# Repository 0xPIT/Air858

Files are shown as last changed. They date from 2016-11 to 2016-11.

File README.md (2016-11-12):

# Air858

Simplified and optimized replacement controller for 
the low-cost W.E.P. 858D+ Hot Air Soldering Station.

## Warning


**This project operates with possibly lethal mains voltage. If you are unsure what to do, don't do it and get help from an experienced tinkerer with professional training.**

## Image of PCB rev. 1
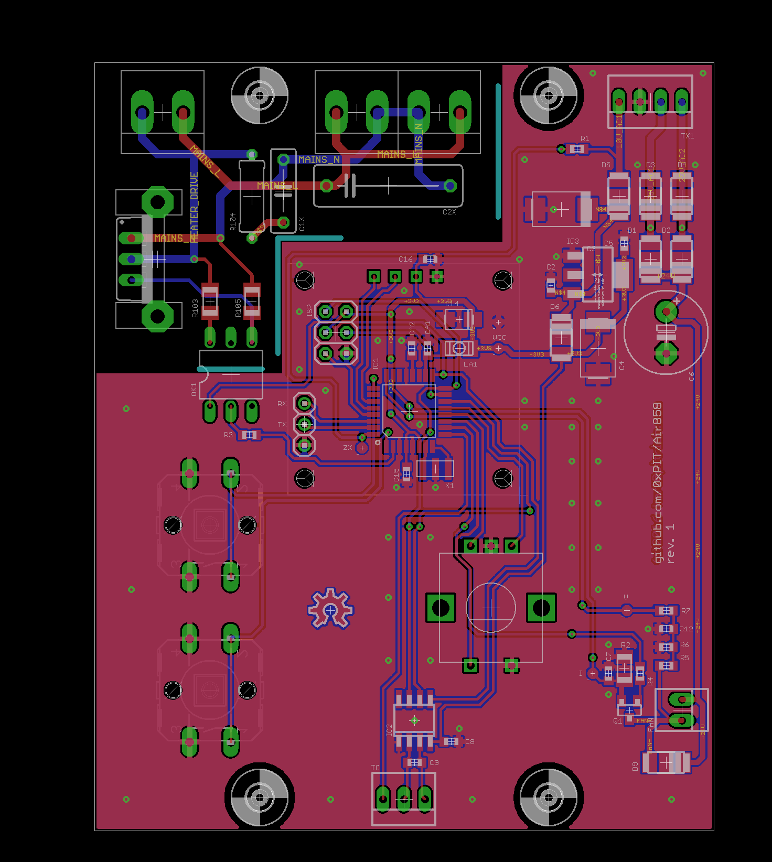
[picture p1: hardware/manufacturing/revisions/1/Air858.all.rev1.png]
BoardAllRev1


Licensing
====================
```
The MIT License (MIT)

Copyright (c) 2016 karl@pitrich.com
All rights reserved.

Permission is hereby granted, free of charge, to any person obtaining a copy
of this software and associated documentation files (the "Software"), to deal
in the Software without restriction, including without limitation the rights
to use, copy, modify, merge, publish, distribute, sublicense, and/or sell
copies of the Software, and to permit persons to whom the Software is
furnished to do so, subject to the following conditions:

The above copyright notice and this permission notice shall be included in
all copies or substantial portions of the Software.

THE SOFTWARE IS PROVIDED "AS IS", WITHOUT WARRANTY OF ANY KIND, EXPRESS OR
IMPLIED, INCLUDING BUT NOT LIMITED TO THE WARRANTIES OF MERCHANTABILITY,
FITNESS FOR A PARTICULAR PURPOSE AND NONINFRINGEMENT. IN NO EVENT SHALL THE
AUTHORS OR COPYRIGHT HOLDERS BE LIABLE FOR ANY CLAIM, DAMAGES OR OTHER
LIABILITY, WHETHER IN AN ACTION OF CONTRACT, TORT OR OTHERWISE, ARISING FROM,
OUT OF OR IN CONNECTION WITH THE SOFTWARE OR THE USE OR OTHER DEALINGS IN
THE SOFTWARE.
```

[BoardAllRev1]:https://raw.githubusercontent.com/0xPIT/Air858/master/hardware/manufacturing/revisions/1/Air858.all.rev1.png

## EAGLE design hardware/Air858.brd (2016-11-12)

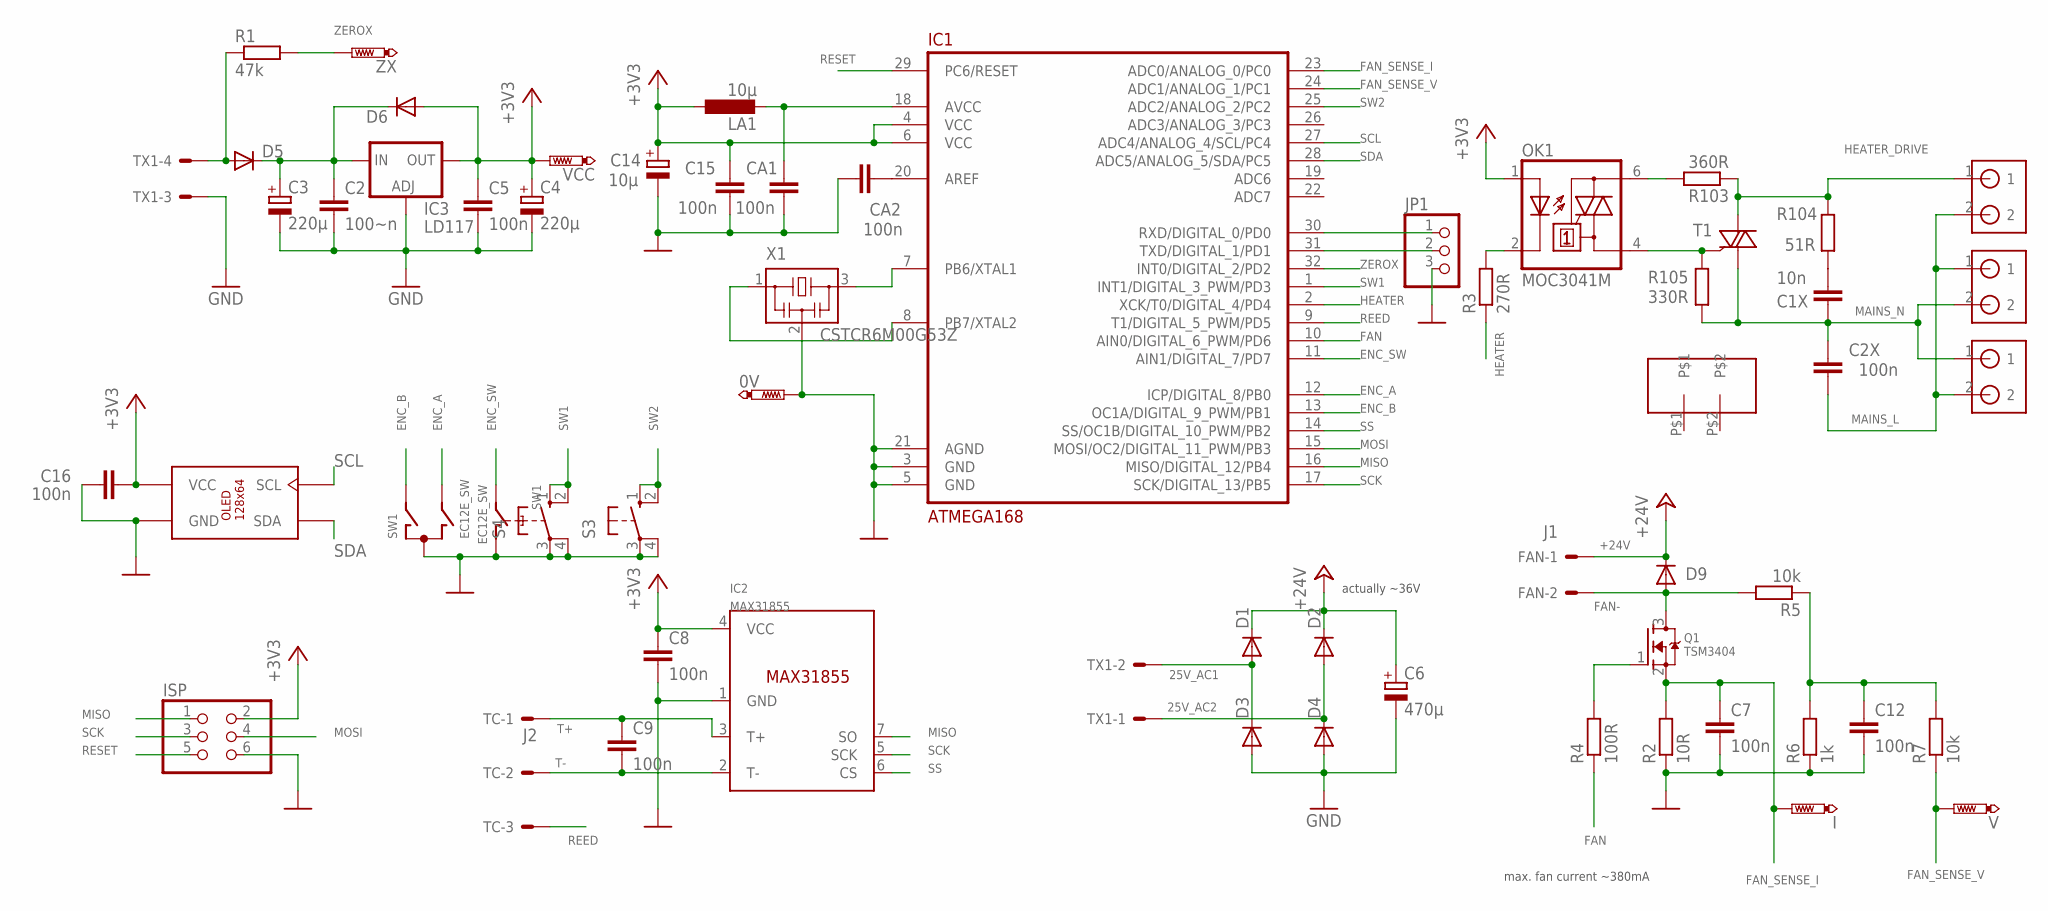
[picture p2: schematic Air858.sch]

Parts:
0V: PTR1B1,27; B1,27
C1X: 10n; C075-032X103
C2: 100~n; C0603
C2X: 100n; C150-054X183
C3, C4: 220µ; SMC_E
C5: 100n; C0603
C6: 470µ; E5-10,5
C7, C8, C9, C12, C15, C16: 100n; C0603K
C14: 10µ; B/3528-21W
CA1, CA2: 100n; C0603K
D1, D2, D3, D4, D5, D6, D9: DIODE-DO-214AC; DO-214AC
FAN: J1; 22-23-2021
HEATER: 2POL5MM
I: PTR1B1,27; B1,27
IC1: ATMEGA168; QFP32
IC2: MAX31855; SOIC8
IC3: LD117; SOT223
ISP: PINHD-2X3; 2X03
JP1: PINHD-1X3; 1X03
LA1: 10µ; L3225P
MAINS1, MAINS2: 2POL5MM
OK1: MOC3041M; DIL06
OLED1: SSD1306-IIC
Q1: TSM3404; SOT23
R1: 47k; R0603
R2: 10R; M1206
R3: 270R; R0603
R4: 100R; R0603
R5, R7: 10k; R0603
R6: 1k; R0603
R103: 360R; M1206
R104: 51R; 0309/10
R105: 330R; M1206
S3, S4: 40-XX; B3F-40XX
SW1: EC12E_SW; ALPS_EC12E_SW
T1: BTA16; TO220BV
TC: J2; 22-23-2031
TX1: J4; 22-23-2041
U$5: HEATSINK17X7.5TO220
V: PTR1B1,27; B1,27
VCC: PTR1B1,27; B1,27
X1: CSTCR6M00G53Z; CSTCR6M
ZX: PTR1B1,27; B1,27

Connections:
10V_AC1: D5.A, R1.1, TX1.4
25V_AC1: D1.A, D3.C, TX1.2
25V_AC2: D2.A, D4.C, TX1.1
+3V3: C4.+, C5.1, C8.1, C14.+, C15.1, C16.2, D6.A, IC1.4 (VCC), IC1.6 (VCC), IC2.4 (VCC), IC3.4 (OUT), ISP.2, LA1.1, OK1.1 (A), OLED1.VCC, VCC.TP
+24V: C6.+, D1.C, D2.C, D9.C, FAN.1
AREF: CA2.2, IC1.20 (AREF)
AVCC: CA1.1, IC1.18 (AVCC), LA1.2
ENC_A: IC1.12 (ICP/DIGITAL_8/PB0), SW1.B
ENC_B: IC1.13 (OC1A/DIGITAL_9_PWM/PB1), SW1.A
ENC_SW: IC1.11 (AIN1/DIGITAL_7/PD7), SW1.E (2)
FAN: IC1.10 (AIN0/DIGITAL_6_PWM/PD6), R4.1
FAN-: D9.A, FAN.2, Q1.3 (D), R5.2
FAN_SENSE_I: C7.1, I.TP, IC1.23 (ADC0/ANALOG_0/PC0), Q1.2 (S), R2.2
FAN_SENSE_V: IC1.24 (ADC1/ANALOG_1/PC1), R7.1, V.TP
GND: 0V.TP, C2.2, C3.-, C4.-, C5.2, C6.-, C7.2, C8.2, C12.2, C14.-, C15.2, C16.1, CA1.2, CA2.1, D3.A, D4.A, IC1.3 (GND), IC1.5 (GND), IC1.21 (AGND), IC2.1 (GND), IC3.1 (ADJ), ISP.6, JP1.3, OLED1.GND, R2.1, R6.1, S3.3, S3.4 (P1), S4.3, S4.4 (P1), SW1.C, SW1.D (1), TX1.3, X1.2
HEATER: IC1.2 (XCK/T0/DIGITAL_4/PD4), R3.1
HEATER_DRIVE: HEATER.1, R103.1, R104.2, T1.T2 (A2)
MAINS_L: C2X.1, HEATER.2, MAINS1.1, MAINS2.2
MAINS_N: C1X.1, C2X.2, MAINS1.2, MAINS2.1, R105.2, T1.T1 (A1)
MISO: IC1.16 (MISO/DIGITAL_12/PB4), IC2.7 (SO), ISP.1
MOSI: IC1.15 (MOSI/OC2/DIGITAL_11_PWM/PB3), ISP.4
unnamed: C12.1, R5.1, R6.2, R7.2
unnamed: OK1.6 (A2), R103.2
unnamed: C2.1, C3.+, D5.C, D6.C, IC3.3 (IN)
unnamed: OK1.2 (C), R3.2
unnamed: OK1.4 (A1), R105.1, T1.G
unnamed: C1X.2, R104.1
unnamed: IC1.7 (PB6/XTAL1), X1.3
unnamed: Q1.1 (G), R4.2
unnamed: IC1.8 (PB7/XTAL2), X1.1
REED: IC1.9 (T1/DIGITAL_5_PWM/PD5), TC.3
RESET: IC1.29 (PC6/RESET), ISP.5
RXD: IC1.30 (RXD/DIGITAL_0/PD0), JP1.1
SCK: IC1.17 (SCK/DIGITAL_13/PB5), IC2.5 (SCK), ISP.3
SCL: IC1.27 (ADC4/ANALOG_4/SCL/PC4), OLED1.SCL
SDA: IC1.28 (ADC5/ANALOG_5/SDA/PC5), OLED1.SDA
SS: IC1.14 (SS/OC1B/DIGITAL_10_PWM/PB2), IC2.6 (CS)
SW1: IC1.1 (INT1/DIGITAL_3_PWM/PD3), S4.1 (S), S4.2 (S1)
SW2: IC1.25 (ADC2/ANALOG_2/PC2), S3.1 (S), S3.2 (S1)
T+: C9.1, IC2.3 (T+), TC.1
T-: C9.2, IC2.2 (T-), TC.2
TXD: IC1.31 (TXD/DIGITAL_1/PD1), JP1.2
ZEROX: IC1.32 (INT0/DIGITAL_2/PD2), R1.2, ZX.TP

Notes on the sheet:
max. fan current ~380mA
actually ~36V

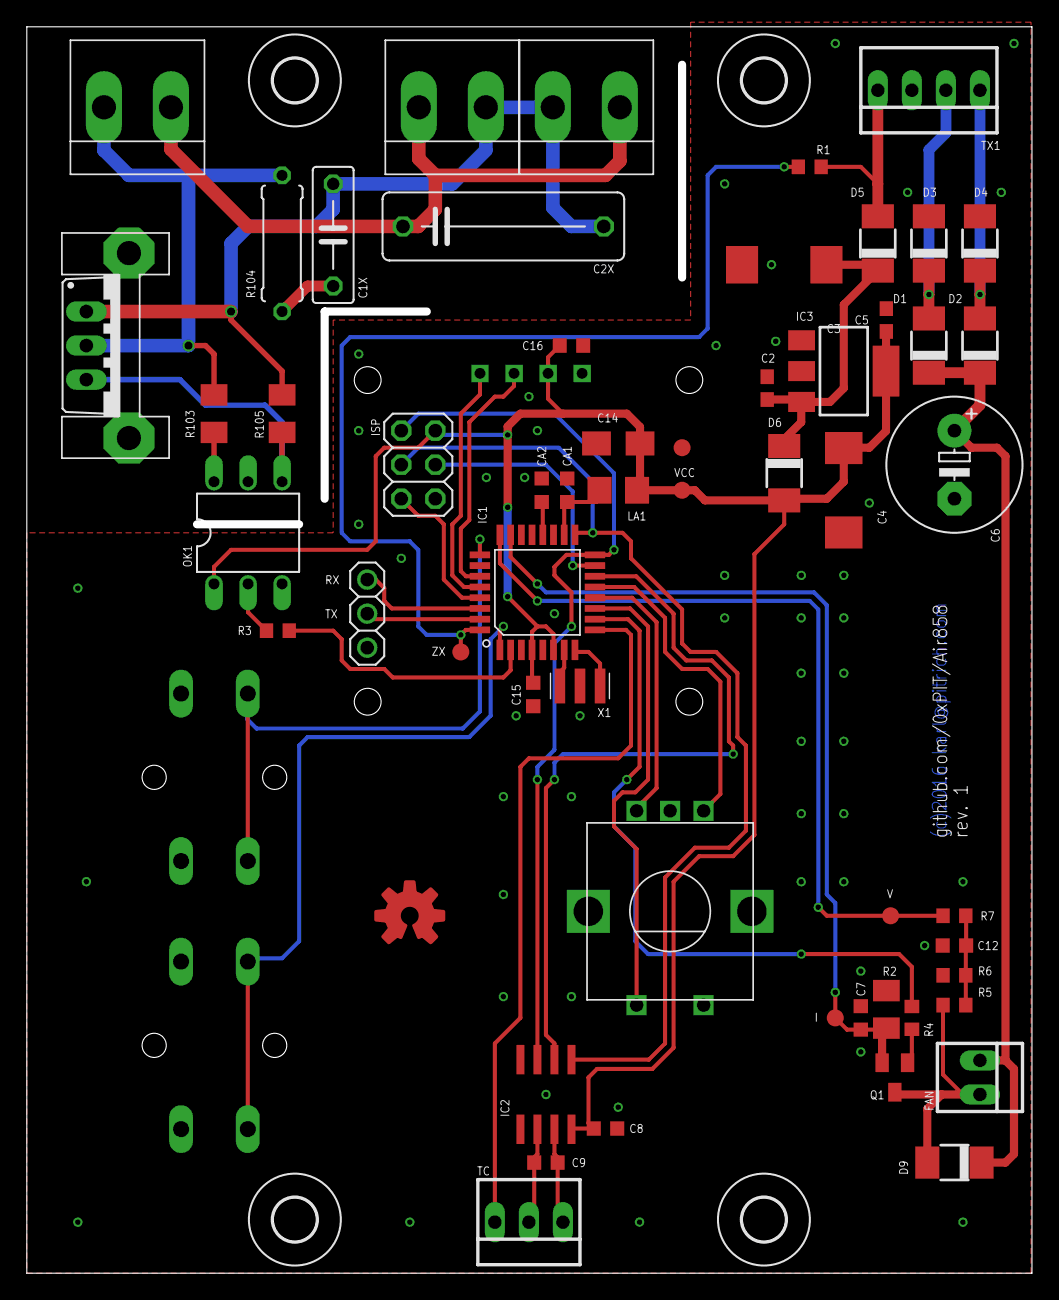
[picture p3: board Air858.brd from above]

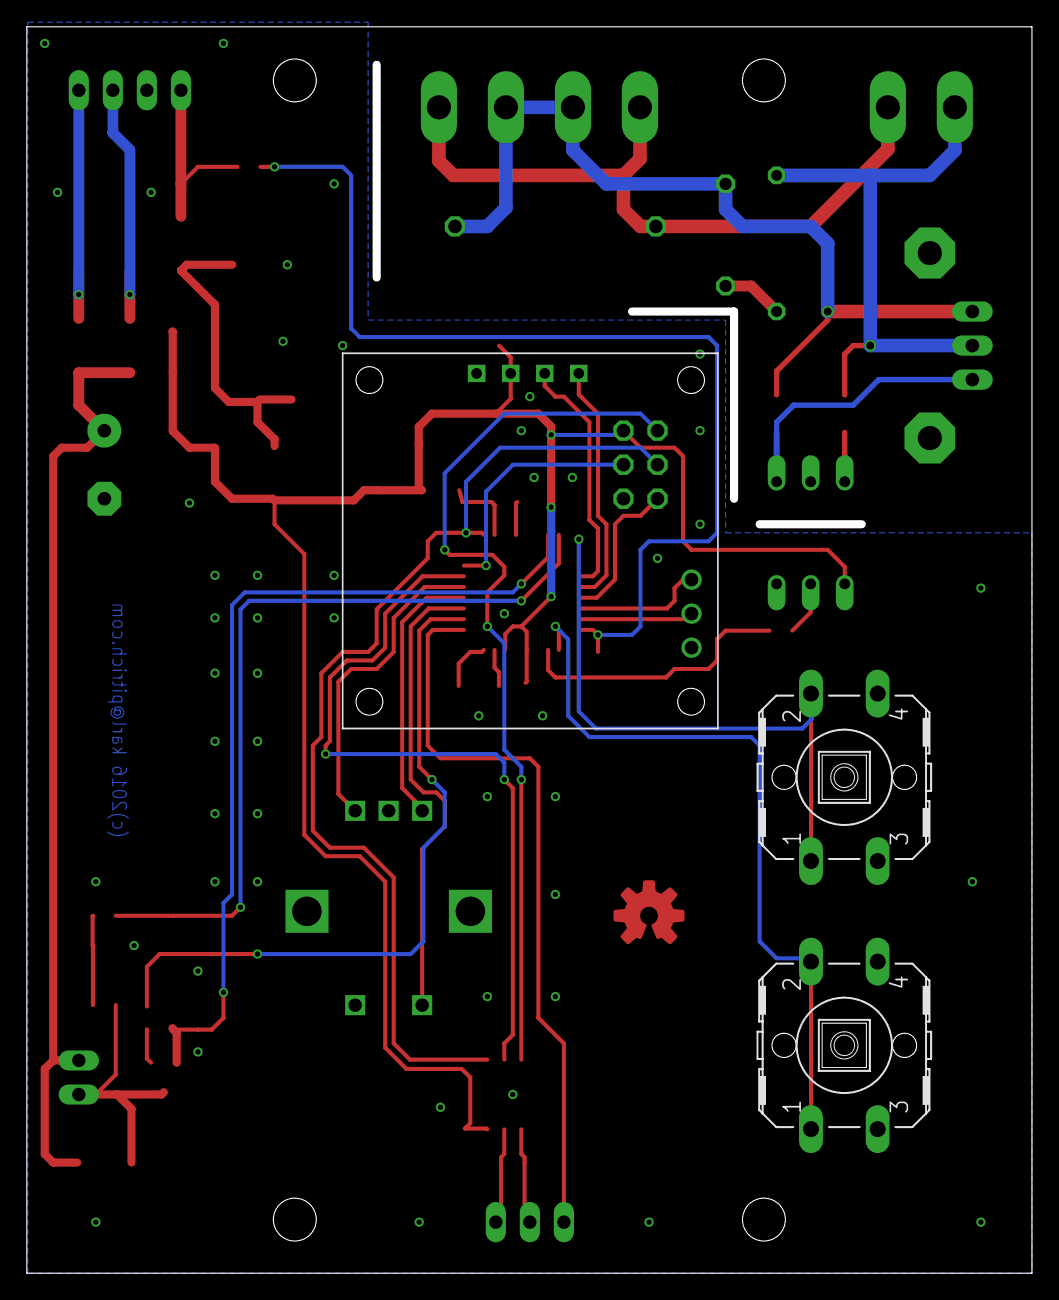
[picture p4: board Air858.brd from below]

Board: 2 copper layers, 75.0 x 93.0 mm, 64 parts (3 on the bottom side), 43 nets.

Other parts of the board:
U$1, U$2, U$3, U$4: 3,2
U$6: OSHWLOGO_TOP_0.2

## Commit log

2016-10-31 initial push of rev.1 pcb
    [Air858.brd, Air858.sch]
2016-11-01 changed zero crossing detection based on AVR182
    [Air858.brd, Air858.sch]
2016-11-02 fix schematic issues and update board
    [Air858.sch]
2016-11-12 rev 1: prototype
    [Air858.GBL, Air858.GBO, Air858.GBP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]
2016-11-12 add board file to rev1 zip
2016-11-12 add board picture
2016-11-12 add oshw logo
    [Air858.brd]
